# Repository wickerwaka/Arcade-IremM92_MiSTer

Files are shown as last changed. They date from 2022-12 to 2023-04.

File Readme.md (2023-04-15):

# This repository is archived. Future core work has been moved to the MiSTer FPGA organization. https://github.com/MiSTer-devel/Arcade-IremM92_MiSTer

# Irem M92 Core

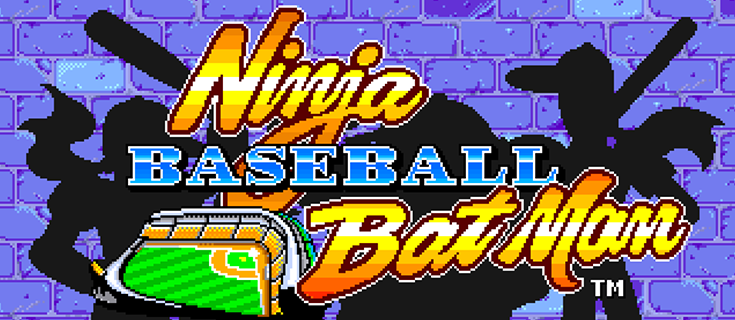
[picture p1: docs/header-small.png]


This is the MiSTer FPGA core for the Irem M92 arcade system (http://www.system16.com/hardware.php?id=747). The Irem M92 system is known for its high-quality graphics and sound, and this core brings these games to the MiSTer platform for arcade enthusiasts to enjoy.

The Irem M92 core includes numerous games that have not been ported elsewhere, providing a unique and authentic arcade experience. Some of the popular games available in this core are:

- In the Hunt
- Gunforce
- R-Type Leo
- Hook
- Blade Master
- Mystic Riders
- Undercover Cops
- Ninja Baseball Batman

## Controls
All of the games use standard 8-way input with two buttons with the exception of *Superior Soldiers* which uses six button input. Several of the games support 3 or 4 players but you will need to change a DIP switch in the DIP switch menu to enable that. By default the button buttons are mapped to the MiSTers SNES-like layout as `B,A,X,Y,L,R`. The `Coin` and `Start` buttons are mapped to Select and Start. There are two additional buttons that can be mapped that are not mapped by default. `P2 Start` maps the the second players start button. The only purpose this serves is for accessing the service menu with a single controller since most games require pressing P1 and P2 start to access it. The second unmapped button is `Pause` which pauses the core.

Standard MAME keyboard controls are also supported for up to 4-players.

## Thanks
Many people, knowingly or not, contributed to this work.
- Mark, for his R-Type Leo PCB and his support through the years.
- @sorgelig, for developing and maintaining MiSTer.
- @RobertPeip, for the v30mz cpu I am using as the basis for the v33 & v35.
- @jotego, for the YM2151 implementation and analog adjustment module.
- @ArtemioUrbina, for their support building [MDfourier](https://junkerhq.net/MDFourier/) tests.
- @zakk4223, for hiscore support.
- @birdybro, @Toryalai1 & @wwark for MRA help.
- Sanborn, for help with the docs.
- The people from PLD Archive collecting and archiving PAL information https://wiki.pldarchive.co.uk/index.php?title=Category:Irem_M92
- The MiSTer FPGA discord server for support, advice and testing.

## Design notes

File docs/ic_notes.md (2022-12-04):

## IC1
M51953A, Reset controller. Holds /RESET (pin 5) signal low for a short time after power up

## IC2
74LS175, Quad flip-flop. Coin counter output. Maybe memcard and rumble? Unknown how it is connected to the CPU.

## IC3
72LS244, Octal Buffer. Test, start, dma busy. Lower Byte

## IC4
72LS244, Octal Buffer. 1P, maybe. Lower Byte

## IC5
72LS244, Octal Buffer. 2P, maybe. Upper Byte

## IC6
72LS244, Octal Buffer. CN4 (4P). Upper Byte

## IC7
72LS244, Octal Buffer. SW2. Upper Byte

## IC8
72F86, Quad XOR. Unknown purpose

## IC9
74ALS273N, Octal flip-flip. Latches RGB value from palette data in IC15. Connected directly to IC15 data lines. CLK/CLR source unknown. Pin 155 on IC63, B2 on CN2.

## IC10
74ALS273N, Octal flip-flip. Latches RGB value from palette data in IC16. Connected directly to IC16 data lines. CLK/CLR source unknown. Pin 155 on IC63, B2 on CN2.

## IC11
PAL16L8. Generates the select signals for the palette ram multiplexers (IC17, 18, etc). Inputs are from the three custom ICs and the videocontrol register. 

## IC12
72LS244, Octal Buffer. CN5 (3P). Lower Byte

## IC13
72LS244, Octal Buffer. SW1. Lower Byte

## IC15 & IC16 "Palette RAM"
MB81C78A, 8k x 8bit SRAM. Two 8K RAMs that are used to store the active color palettes. The ICs 17, 18, 19, 25, 26, 27, 28 multiplex the address lines, which are selected by IC11.

IC63 and the B Board address this RAM in order to latch color output values to the output flipflops (IC9 & IC10). The CPU and IC42 have read and write access to this RAM, but in general use the CPU does not access it and IC42 only writes to it during its DMA transfer.

The output enable and chip select signals are always asserted. 

## IC17, IC18, IC19, IC25, IC26, IC27, IC28
74LS153, multiplexers. Multiplexes shared ram address lines and write enable.

| Channel | Source |
|---|---|
| 0 | CPU |
| 1 | IC42 |
| 2 | IC63 |
| 3 | B Board |

## IC37 & IC38 Buffer RAM
Buffers palette and obj data before being copied to palette RAM (IC15/16) and OBJ RAM (IC43/44). All access to it is through IC42.

## IC43/44 OBJ RAM
OBJ data copied from IC37/38. Addressed by IC42, read by IC63.

## IC46
74LS138, 3-8 decoder. Selects 244 buffers based on IO port address. Address lines A1-A3 are hooked up to ABC inputs. Not sure how enables are hooked up.

## IC55
72LS244, Octal Buffer. SW3. Upper Byte

## IC56 & IC57
CPU data bus drivers.

## IC58, IC59, IC60
CPU address bus drivers.

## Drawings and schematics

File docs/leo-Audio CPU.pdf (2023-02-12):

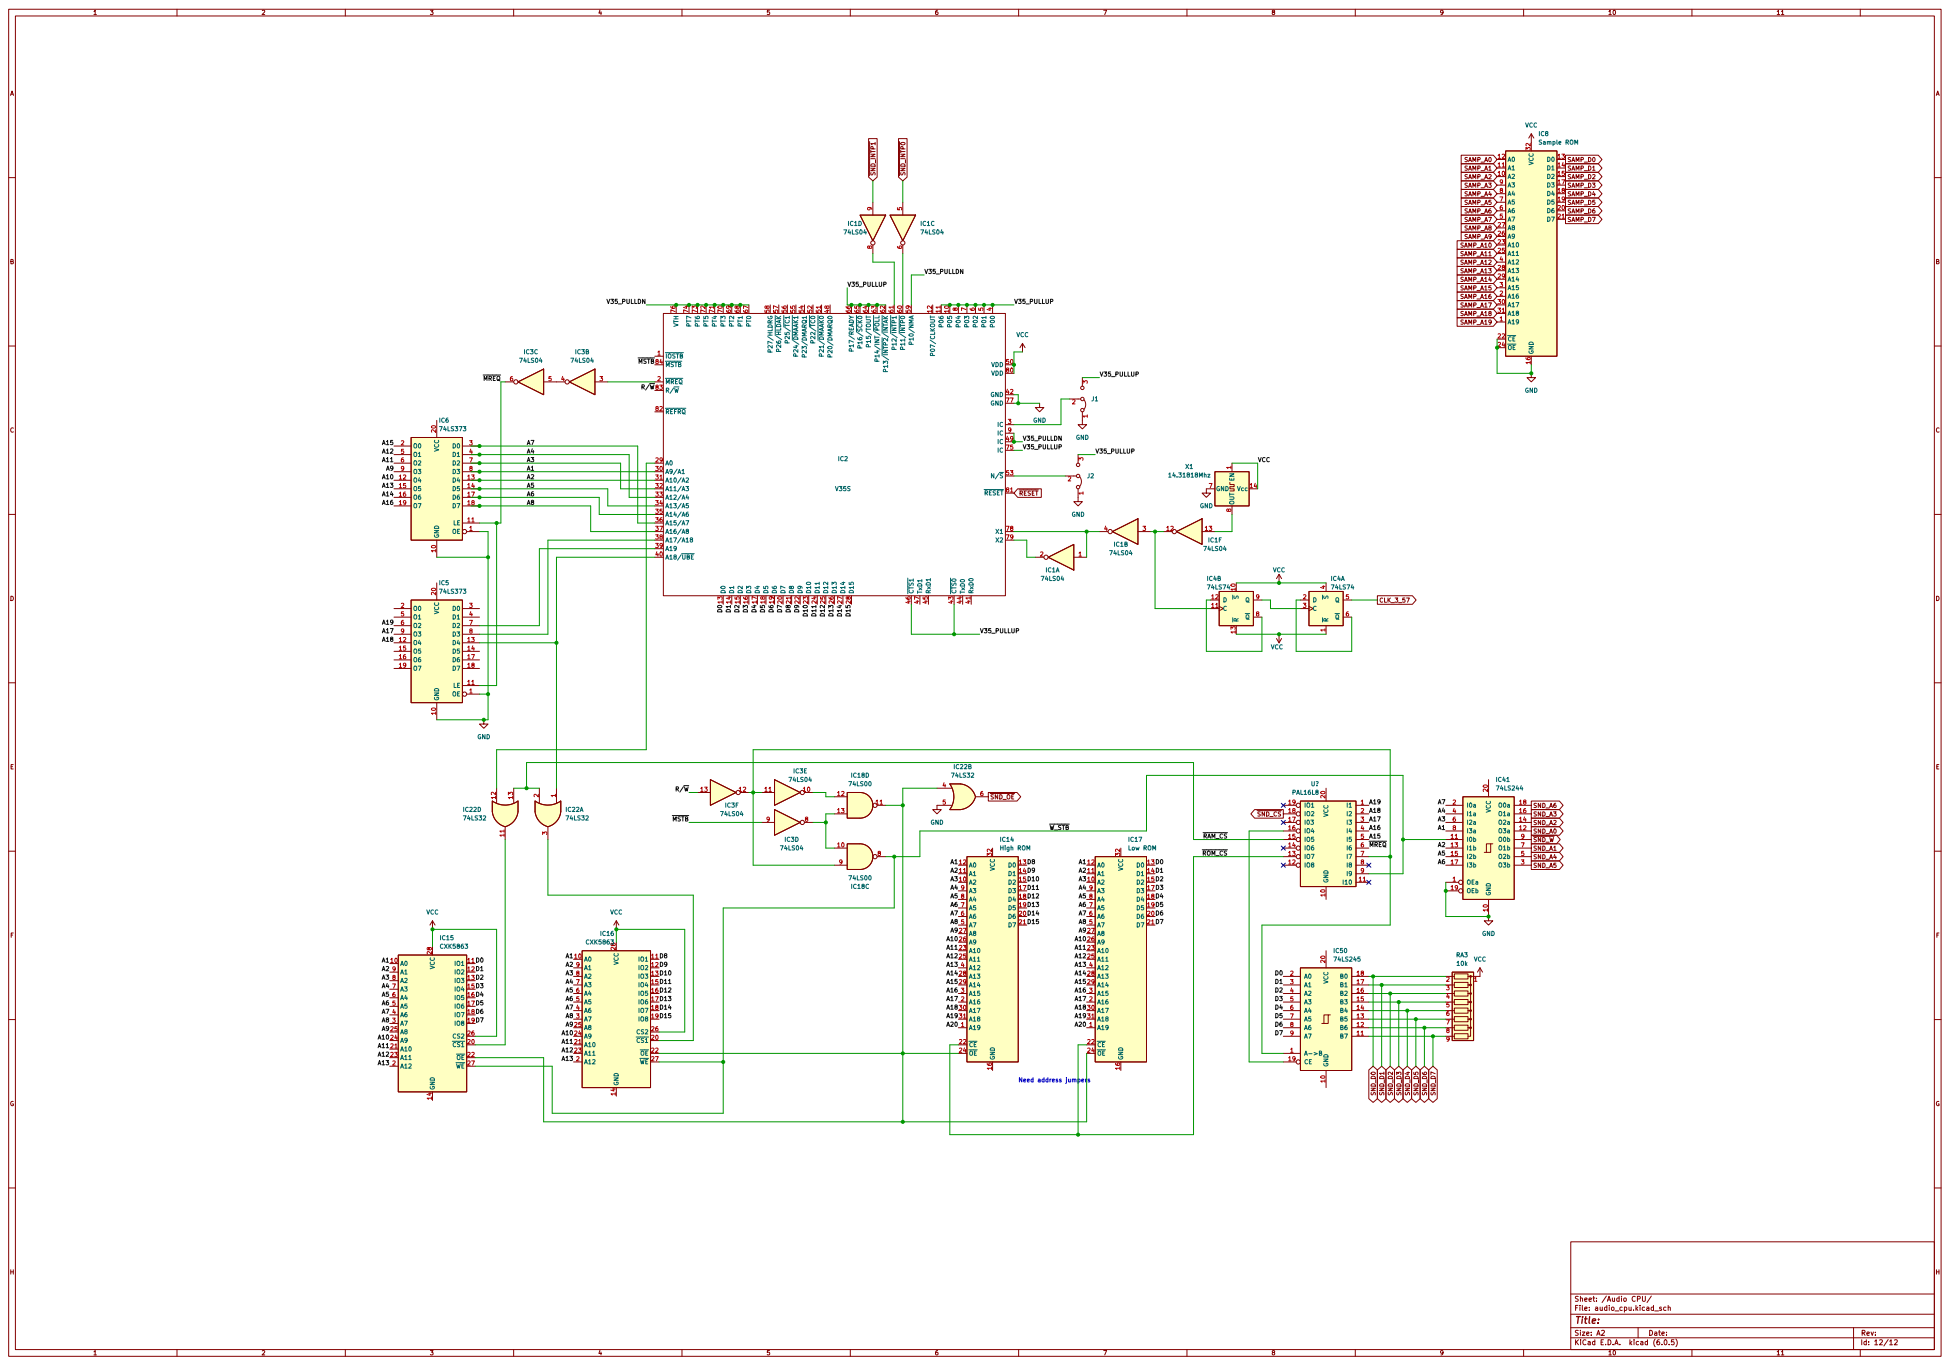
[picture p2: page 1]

16 B1
15 B2
14 B3
13 B4
12 B5
11 B6

File: audio_cpu.kicad_sch Sheet: /Audio CPU/

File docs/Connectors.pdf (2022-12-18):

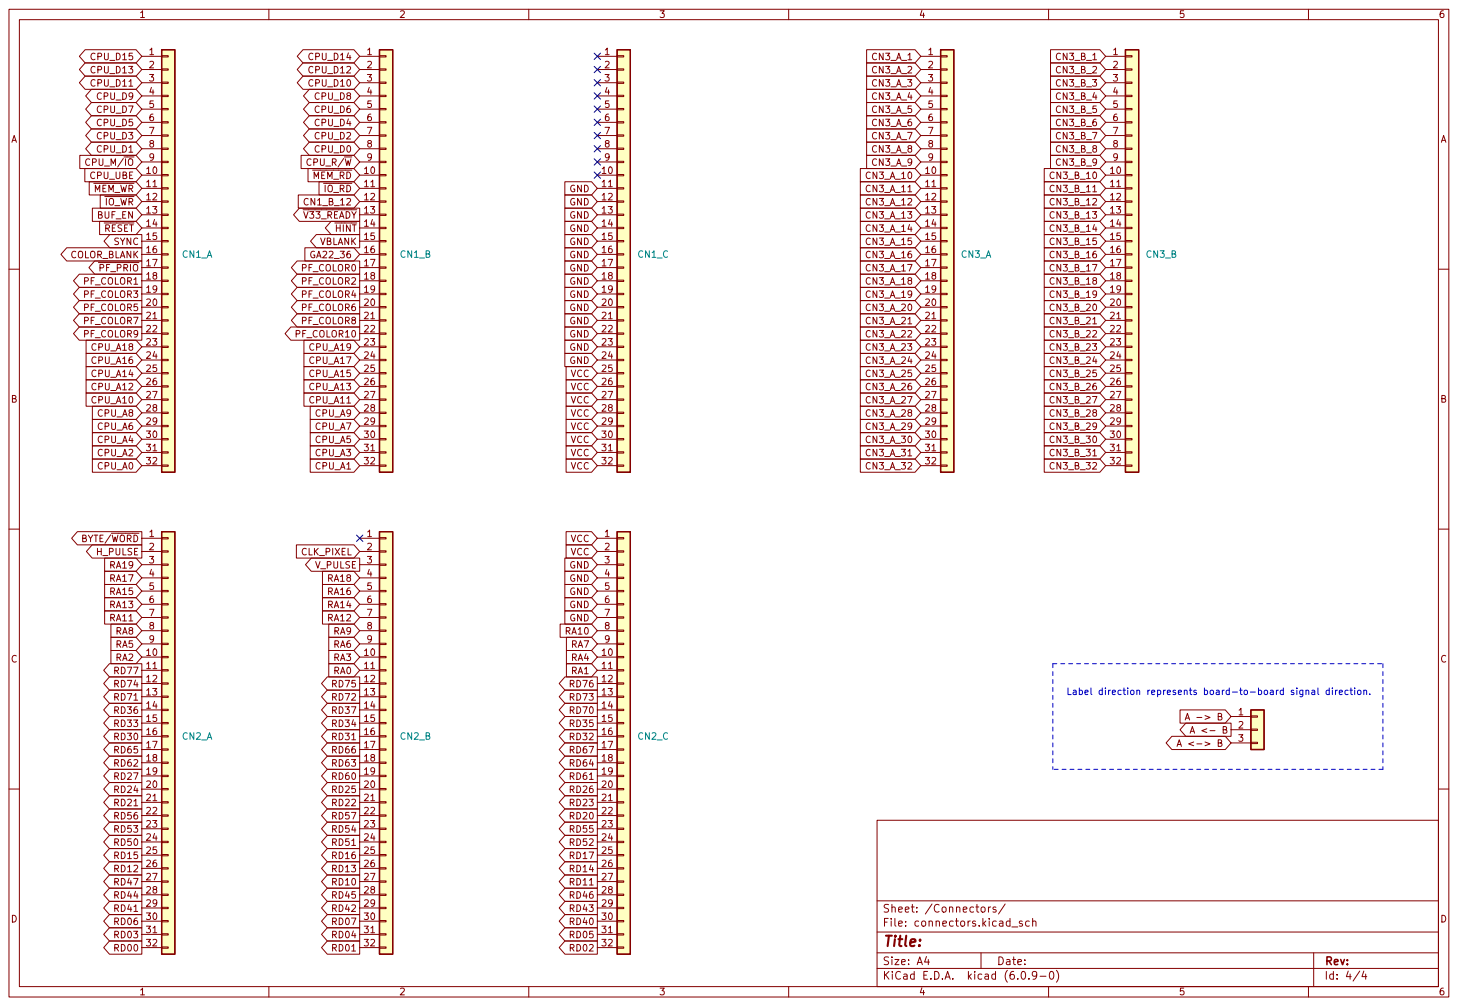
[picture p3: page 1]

Label direction represents board-to-board signal direction.

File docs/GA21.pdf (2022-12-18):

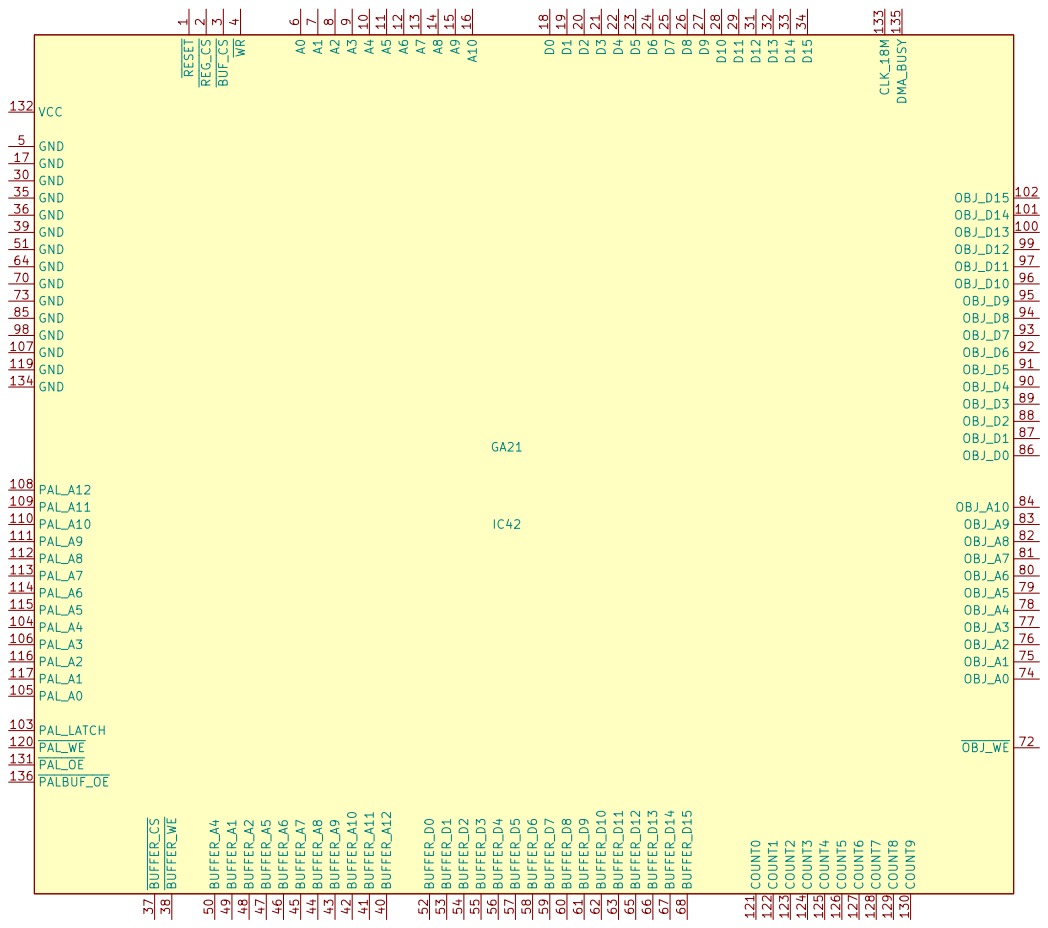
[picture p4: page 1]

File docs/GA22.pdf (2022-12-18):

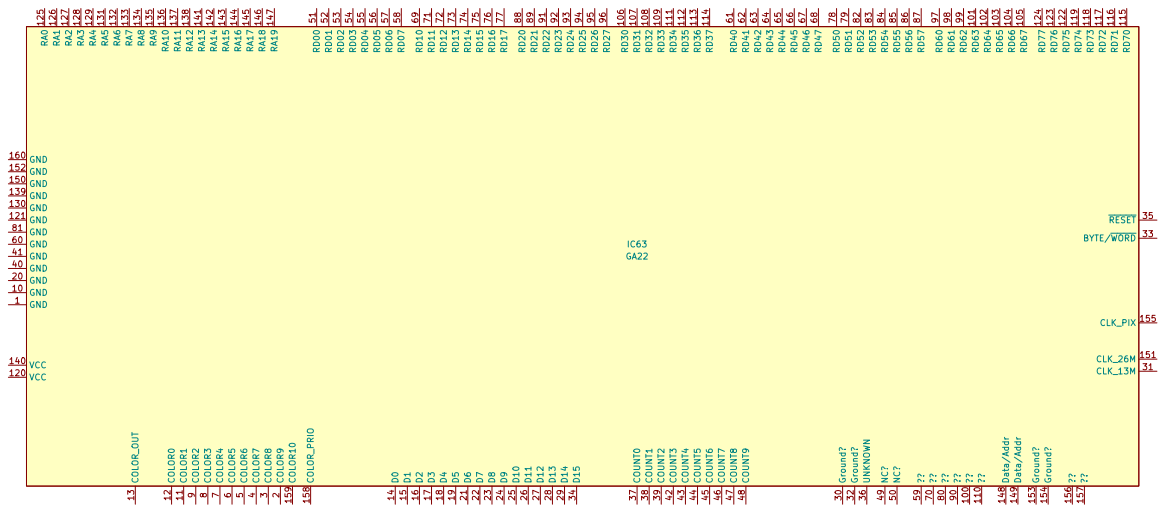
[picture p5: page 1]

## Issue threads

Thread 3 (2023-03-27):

button mapping naming convention

konradpop, 2023-03-27:
all games refer to the in the hunt button naming labels. Should be specific for each core.

Toryalai1, 2023-03-29:
This is now solved: https://github.com/wickerwaka/Arcade-IremM92_MiSTer/commit/d0b53fa7cf9b42c7385ee8c4a7476eb1ae37a922

wickerwaka, 2023-03-29:
Yes, thank you got the names list @Toryalai1

Closed 2023-03-29.

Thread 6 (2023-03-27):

55hz mode outputs 60hz instead

Sheeg, 2023-03-27:
Even if I set my a 55hz video mode in my MiSTer ini file, the core will load at 55hz initially, then immediately switch to 60hz after the rom is loaded, toggling the video modes in the menu does nothing.

Hopefully this is known, but just posting here so it's tracked.

wickerwaka, 2023-03-29:
This is an old option left over from the M72 code. M92 hardware runs at a pretty standard 60hz, so no need for video timing toggles. The option has been removed in 16bdfba8b5ffe095bf7763aee970a269969134ae

Closed 2023-03-29.

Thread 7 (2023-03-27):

P2 Start

misteraddons, 2023-03-27:
P2 Start maps to player 1 controls for debugging purposes. Perhaps adding logic to allow P2 Start from P1. Perhaps add an OR statement to accept "P2 Start" button from joystick 1, or "Start" from joystick 2.
`wire m_start2   = btn_2p_start | joy[10] | joystick_1[8];`

wickerwaka, 2023-03-29:
Fixed 16bdfba8b5ffe095bf7763aee970a269969134ae

Closed 2023-03-29.

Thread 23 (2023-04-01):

No loading using the core

Jackburton69, 2023-04-01:
Hello,
I using your core on a Mister2jamma.
When i load any game from your core i don't have the loading splash screen like any other core on the MiSTer.
I saw the check of the ram but nothing else (i can see the core option when i push the correct button)
If i try and retry sometime i can go the the splash screen of the game (Ninjabaseball for ex) but nothing else.

This is normal to don't have the loading splash screen with the loading of the rom ?

I attached what I have on the ram check screen

Best
!
[IMG_20230329_232811](https://user-images.githubusercontent.com/74626824/229290338-5f6c72fb-fb04-43cd-9800-7ea55b5ed1ff.jpg)

Toryalai1, 2023-04-05:
The core is still in alpha state so please wait until it is in beta/released state. The core is being updated and stuff that wouldn't today might work tomorrow

This can be closed

wickerwaka, 2023-04-07:
40c060f5f184e92dc46cf664fbd1cc6174007552 has restored support for keyboard encoders.

Closed 2023-04-07.

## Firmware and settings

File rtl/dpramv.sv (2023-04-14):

//============================================================================
//  Copyright (C) 2023 Martin Donlon
//
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
`timescale 1ns / 1ps

module dualport_ram #(
    parameter width = 8,
    parameter widthad = 10
) (
    // Port A
    input   wire                  clock_a,
    input   wire                  wren_a,
    input   wire    [widthad-1:0] address_a,
    input   wire    [width-1:0]   data_a,
    output  reg     [width-1:0]   q_a,

    // Port B
    input   wire                  clock_b,
    input   wire                  wren_b,
    input   wire    [widthad-1:0] address_b,
    input   wire    [width-1:0]   data_b,
    output  reg     [width-1:0]   q_b
);

// Shared ramory
reg [width-1:0] ram[(2**widthad)-1:0];

// Port A
always @(posedge clock_a) begin
    if (wren_a) begin
        ram[address_a] <= data_a;
        q_a <= data_a;
    end else begin
        q_a <= ram[address_a];
    end
end

// Port B
always @(posedge clock_b) begin
    if(wren_b) begin
        q_b      <= data_b;
        ram[address_b] <= data_b;
    end else begin
        q_b <= ram[address_b];
    end
end

endmodule

module singleport_ram #(
    parameter width = 8,
    parameter widthad = 10,
    parameter name = "NONE"
) (
    input   wire                   clock,
    input   wire                   wren,
    input   wire    [widthad-1:0]  address,
    input   wire    [width-1:0]    data,
    output  reg     [width-1:0]    q

);

altsyncram	altsyncram_component (
            .address_a (address),
            .clock0 (clock),
            .data_a (data),
            .wren_a (wren),
            .q_a (q),
            .aclr0 (1'b0),
            .aclr1 (1'b0),
            .address_b (1'b1),
            .addressstall_a (1'b0),
            .addressstall_b (1'b0),
            .byteena_a (1'b1),
            .byteena_b (1'b1),
            .clock1 (1'b1),
            .clocken0 (1'b1),
            .clocken1 (1'b1),
            .clocken2 (1'b1),
            .clocken3 (1'b1),
            .data_b (1'b1),
            .eccstatus (),
            .q_b (),
            .rden_a (1'b1),
            .rden_b (1'b1),
            .wren_b (1'b0));
defparam
    altsyncram_component.clock_enable_input_a = "BYPASS",
    altsyncram_component.clock_enable_output_a = "BYPASS",
    altsyncram_component.intended_device_family = "Cyclone V",
    altsyncram_component.lpm_hint = {"ENABLE_RUNTIME_MOD=NO,INSTANCE_NAME=", name},
    altsyncram_component.lpm_type = "altsyncram",
    altsyncram_component.numwords_a = 2**widthad,
    altsyncram_component.operation_mode = "SINGLE_PORT",
    altsyncram_component.outdata_aclr_a = "NONE",
    altsyncram_component.outdata_reg_a = "CLOCK0",
    altsyncram_component.power_up_uninitialized = "FALSE",
    altsyncram_component.ram_block_type = "M10K",
    altsyncram_component.read_during_write_mode_port_a = "DONT_CARE",
    altsyncram_component.widthad_a = widthad,
    altsyncram_component.width_a = width,
    altsyncram_component.width_byteena_a = 1;


endmodule

module singleport_unreg_ram #(
    parameter width = 8,
    parameter widthad = 10,
    parameter name = "NONE"
) (
    input   wire                   clock,
    input   wire                   wren,
    input   wire    [widthad-1:0]  address,
    input   wire    [width-1:0]    data,
    output  wire    [width-1:0]    q
);

altsyncram	altsyncram_component (
            .address_a (address),
            .clock0 (clock),
            .data_a (data),
            .wren_a (wren),
            .q_a (q),
            .aclr0 (1'b0),
            .aclr1 (1'b0),
            .address_b (1'b1),
            .addressstall_a (1'b0),
            .addressstall_b (1'b0),
            .byteena_a (1'b1),
            .byteena_b (1'b1),
            .clock1 (1'b1),
            .clocken0 (1'b1),
            .clocken1 (1'b1),
            .clocken2 (1'b1),
            .clocken3 (1'b1),
            .data_b (1'b1),
            .eccstatus (),
            .q_b (),
            .rden_a (1'b1),
            .rden_b (1'b1),
            .wren_b (1'b0));
defparam
    altsyncram_component.clock_enable_input_a = "BYPASS",
    altsyncram_component.clock_enable_output_a = "BYPASS",
    altsyncram_component.intended_device_family = "Cyclone V",
    altsyncram_component.lpm_hint = {"ENABLE_RUNTIME_MOD=NO,INSTANCE_NAME=", name},
    altsyncram_component.lpm_type = "altsyncram",
    altsyncram_component.numwords_a = 2**widthad,
    altsyncram_component.operation_mode = "SINGLE_PORT",
    altsyncram_component.outdata_aclr_a = "NONE",
    altsyncram_component.outdata_reg_a = "UNREGISTERED",
    altsyncram_component.power_up_uninitialized = "FALSE",
    altsyncram_component.ram_block_type = "M10K",
    altsyncram_component.read_during_write_mode_port_a = "DONT_CARE",
    altsyncram_component.widthad_a = widthad,
    altsyncram_component.width_a = width,
    altsyncram_component.width_byteena_a = 1;

endmodule

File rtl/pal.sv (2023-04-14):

//============================================================================
//  Irem M92 for MiSTer FPGA - PAL address decoders
//
//  Copyright (C) 2023 Martin Donlon
//
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

import m92_pkg::*;

module address_translator
(
    input logic [19:0] A,

    input logic [3:0] bank_select,
  
    input board_cfg_t board_cfg,

    output [24:0] sdr_addr,
    output writable,
    output ram_rom_memrq,

    output buffer_memrq,
    output sprite_control_memrq,
    output video_control_memrq,
    output pf_vram_memrq,
	output eeprom_memrq
);

wire [3:0] bank_a19_16 = ( bank_select & board_cfg.bank_mask ) | ( A[19:16] & ~board_cfg.bank_mask );

always_comb begin
    ram_rom_memrq = 0;
    writable = 0;
    sdr_addr = 0;

    buffer_memrq = 0;
    sprite_control_memrq = 0;
    video_control_memrq = 0;
    pf_vram_memrq = 0;
	eeprom_memrq = 0;

	casex (A[19:0])
	// 0xc0000-0xcffff
	20'b1100_xxxx_xxxx_xxxx_xxxx: begin ram_rom_memrq = 1; writable = 0; sdr_addr = { REGION_CPU_ROM.base_addr[24:16], A[15:0] }; end
	// 0xd0000-0xdffff
	20'b1101_xxxx_xxxx_xxxx_xxxx: pf_vram_memrq = 1;
	// 0xe0000-0xeffff
	20'b1110_xxxx_xxxx_xxxx_xxxx: begin ram_rom_memrq = 1; writable = 1; sdr_addr = { REGION_CPU_RAM.base_addr[24:16], A[15:0] }; end
	// 0xf0000-0xf3fff
	20'b1111_00xx_xxxx_xxxx_xxxx: eeprom_memrq = 1;
	// 0xf8000-0xf87ff
	20'b1111_1000_xxxx_xxxx_xxxx: buffer_memrq = 1;
	// 0xf9000-0xf900f
	20'b1111_1001_0000_0000_xxxx: sprite_control_memrq = 1;
	// 0xf9800-0xf9801
	20'b1111_1001_1000_0000_000x: video_control_memrq = 1;
	// 0xffff0-0xfffff
	20'b1111_1111_1111_1111_xxxx: begin ram_rom_memrq = 1; writable = 0; sdr_addr = { REGION_CPU_ROM.base_addr[24:20], 16'h7fff, A[3:0] }; end
	// 0x00000-0xbffff
	default: begin
		if (board_cfg.alt_map && A[19:16] == 4'h8) begin
			pf_vram_memrq = 1;
		end else begin
			ram_rom_memrq = 1;
			writable = 0;
			sdr_addr = { REGION_CPU_ROM.base_addr[24:20], A[19:17] == 3'b101 ? bank_a19_16 : A[19:16], A[15:0] };
		end
	end
	endcase
end
endmodule

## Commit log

2021-07-10 Add VCD trace and model save/load (naeloob), reorg windows
2022-06-16 Implemented PAL 4D Fixed ram writes. x86 core is progressing through ram test Needs interrupts
    [pal.sv]
2022-06-17 First pass on tilemap rendering Logic is in place, but there are still issues with addressing Color palettes not hooked up yet HINT is hooked up, but doesn't appear to be working correctly
    [pal.sv]
2022-06-23 Got first version up and running on DE-10
    Moved cpu ram/rom to sdram
    Sprites just using a single plane right now
    Moving sprites to sdram next
    Added joystick and dip switch input
    [stp1.stp]
2022-06-25 Moved sprite rom to SDRAM and fixed sprite rendering. Added back sound ram now that there is room. Changed DCLK to CE_PIX clock enables Some problems with background colors.
    [stp1.stp]
2022-07-23 Switch to wonderswan v30mz cpu implementation. Stubbed in missing v30 opcodes to prevent crashing. Updated kna90h015 to better match furrtek's reverse engineered info. Used ic75 and ic66 roms from ma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
    [pal.sv]
2022-07-25 Split b_d board signals into memory and io Fix background glitching issues Start work on pause
    [pal.sv]
2022-07-25 Add R-Type (Japan prototype).mra
2022-07-27 Add all dip switches and set recommended defaults New rbf
2022-07-28 Several fixes
    Fix horizontally flipped tiles, most obvious in second r-type level.
    Add pause support. Preserve vertical and horizontal tile offsets so they can be replayed during pause.
    Add pause button to mra files
    Add scandoubling support.
    Add integer scaling support.
    Clean up OSD.
2022-08-03 Add 50Hz, 57Hz and 60Hz modes. Clean up some warnings.
2022-08-05 Moved all rom data to sdram Switch to 4 read bursts Start adapting memory layout for other m72 games
2022-08-06 Added support for Gallop Samples missing Updated mras to match new format Added support for additional V30 opcodes
2022-08-06 M84 Schematics / NEC documentation / Generic M72 MRAs
    R-TYPE II top board schematics for M-84-A-A board and OPCODES for NEC V20/30-V25/35 with manuals.
    Generic M72 MRA files for i8751 Japanese MCU ROM files. Will need to be reworked for your memory banking. Layout based on the largest ROM for Irem M72-84 hardware.
2022-08-16 Enable framebuffer
2022-08-17 Add proper support for more than 2 buttons Fix up mras to support 4 buttons Fix hang in Image Fight second level (AAA and AAS were incorrectly updating AH) Wire up second audio latch
    [pal.sv]
2022-08-23 Stall 8051 when writing to shared external memory since mcu runs too fast in general Separate mcu and cpu clock enable Add sample playback support Fix vertically flipped sprites position Reduce cpu p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
2022-08-24 Add Dragon Breed and Mr. HELI Clean up formatting and default button assignment
2022-08-24 - Added Dragon Breed, Mr. Heli and Legend of Hero Tonma - Fix issues with screen flipping. Sprites are now flipped correctly and offset correctly with the background. - Corrected off-by-one error for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
2022-08-26 X-Multiply and Air Duel
    improved layer sdram timing
    mask lower priority interrupts while intp is held high
    add missing latch from kna70h015
    Change board_type to board_cfg
    Added mculatch specialcase for airduel
    [pal.sv]
2022-08-30 Add some low pass filtering to samples and ym audio
    Thanks to @_ShootTheCore for providing original hardware recordings to test against.
    It's not a perfect match yet, but it gets the relative audio levels correct and the filtering is a close match. More adjustments can be made later.
2022-08-30 Add filtering debug option
2022-08-31 Switch gamma to gamma_fast so it doesn't require a 4x pixel clock Cleaned up some warnings Add license header to all files
    [pal.sv]
2022-08-31 Update X Multiply (Japan, M72 hardware).mra
    Fix demo sounds switch, thanks @birdybro
2022-09-02 Support sample playback in gallop Emulates the mcu similar to how MAME does it
2022-09-02 - Emulated MCU support for cores with missing MCU dumps - Added Daiku no Gensan (Hammerin' Harry) - Added sample playback to Gallop
2022-09-09 New Features - Support for R-Type 2, M84 hardware - Added 240p crop option - Added Analog video h/v adjustments
    Internal Changes
    - Added jtframe_resync for analog video adjustments
    - Moved sample rom to a separate module so it can be shared by mcu and z80
    - Changed the almost direct PAL implementations with an address_translator module that does all of the original 3 PAL logic and also supports M84 addressing modes
    - Increased background layer SDRAM address size and support single background rom for M84
    - Added support for M84 tile addressing.
    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
2022-09-13 Fixes and improvements from @gyurco - Support Hammerin' Harry M84 - M84 sample playback rate fixes - Reduce sprite bram usage
    [pal.sv]
2022-10-29 Notes and some initial schematics
    [leo.kicad_pcb, leo.kicad_sch, shared_memory.kicad_sch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]
2022-11-11 Additional schematic updates
    [clock_gen.kicad_sch, leo.kicad_sch, shared_memory.kicad_sch]
2022-12-02 Renamed shared ram
    [leo.kicad_sch, palette_ram.kicad_sch]
2022-12-15 schematic updates
    [leo.kicad_sch, palette_ram.kicad_sch]
2022-12-17 Fixed up label names Added connectors sheet
    [connectors.kicad_sch, leo.kicad_sch, palette_ram.kicad_sch]
2022-12-17 Name most of the CN1 and CN2 pins
    [connectors.kicad_sch, leo.kicad_sch]
2022-12-17 Fill in word data signals based on pattern
    [connectors.kicad_sch]
2022-12-18 Clean up connectors
    [connectors.kicad_sch, leo.kicad_sch]
2022-12-18 Added GA21 sheet
    [ga_21.kicad_sch, leo.kicad_sch]
2022-12-18 Added GA22 symbol
    [ga21.kicad_sch, ga22.kicad_sch, leo.kicad_sch]
2022-12-19 Add VRAM and B board interface
    [b_interface.kicad_sch, leo.kicad_sch, vram.kicad_sch]
2022-12-20 Add more b board logic
    [b_board_support.kicad_sch, b_interface.kicad_sch, connectors.kicad_sch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]
2022-12-20 Split bank switching into its own sheet
    [b_board_support.kicad_sch, bank_switching.kicad_sch, leo.kicad_sch]
2022-12-21 Decode M92-B-7H-D PAL
    [b_board_support.kicad_sch, b_interface.kicad_sch, bank_switching.kicad_sch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]
2022-12-21 Rough out 08J27504
    [b_interface.kicad_sch]
2023-01-04 Name video control bits Correct palette addressing
    [leo.kicad_sch, palette_ram.kicad_sch]
2023-01-07 Fix vram addressing edge case
2023-01-11 Add bank switching support Disable dma busy irq, fixed r-type score display (why?) Remove additional line Add support for 3rd set of dipswitches Fix Ninja Baseball mra, boots but hangs
    [pal.sv]
2023-02-08 Added ga20 sample channel filters
    [leo.kicad_sch, sample_filters.kicad_sch]
2023-02-11 Map out most of audio cpu
    [audio_cpu.kicad_sch, leo.kicad_sch, sample_filters.kicad_sch]
2023-02-12 B Board Audio section complete
    [audio_cpu.kicad_sch, connectors.kicad_sch]
2023-02-12 Missing files
    [leo.kicad_sch]
2023-02-14 Finished GA20 pinout Roughed in sound latch, ym2151 and ga20 signals in A board
    [audio.kicad_sch, audio_cpu.kicad_sch, connectors.kicad_sch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]
2023-02-15 Add NL pin Remove unconnected GA23 pins
    [audio.kicad_sch, connectors.kicad_sch]
2023-03-19 SFR stuff
    Generated an SFR table from the v35 docs
    Python script to generate reset and read/write blocks
    [v35_sfr.csv]
2023-03-22 Add 4th sdram channel for sample data
2023-03-25 Some very crackly samples working
2023-03-26 Add ym filters and misinx path Upgrade to kicad 7
    [audio.kicad_sch, audio_cpu.kicad_sch, audio_mix.kicad_sch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]
2023-03-26 Fix random initialization issues. Timing on samples still seems off
2023-03-29 Update button names and dip switches
2023-03-29 Fix PIC behavior with overlapping interrupts Enable dma sprite dma irq
2023-03-29 Support vidctrl buffer switching Split bufram up into 4 banks in order to maintain unregistered ram reads.
2023-03-30 Lethal Thunder Support for Lethal Thunder memory map Added Major Title 2 mra, but missing EEPROM support
    Fixes #22
    Partially addresses #14
    [pal.sv]
2023-03-30 New build
    3-4 player support
    Pause implemented
    Lethal Thunder Supported
    Sample playback timing fixed.
2023-03-31 Update alternative mras with dip switch and audio keys
    Thanks to wark91
2023-04-01 Update button
2023-04-03 Decide which interrupt is the highest priority when the request is acknowledged, not when it is trigger.
2023-04-05 Support for 6 buttons with kick harness config
2023-04-05 Update button mapping for 6 buttons
2023-04-07 New RBF build Add board type for additional tileset usage
2023-04-09 H and V positioning Support larger offsets Invert direction so it matches shoulder button adjustment
2023-04-11 Replace inferred RAM with megafunction Remove hacks needed to work around ram inference issues
    [dpramv.sv]
2023-04-13 Adjust pcm and fm levels, add clipping Fix sample status reading
2023-04-13 Reduce sample filters down to a single one for all four channels Increased overall volume Matched PCM and YM2151 levels to original hardware
    Fixes: #19
2023-04-14 Clean up docs directory
    [audio.kicad_sch, audio_cpu.kicad_sch, audio_mix.kicad_sch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]
2023-04-14 Remove unused or unsupported dip switches
2023-04-14 Clean up filter generation

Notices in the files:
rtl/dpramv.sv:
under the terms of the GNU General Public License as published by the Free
